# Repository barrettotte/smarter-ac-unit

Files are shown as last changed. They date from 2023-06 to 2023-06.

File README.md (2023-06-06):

# smarter-ac-unit

Making my AC unit a little smarter with MQTT and Home Assistant

## Summary

Uses Home Assistant, MQTT, and an infrared transmitter to control parts of my AC unit that I care about. 
This is only meant to work with my AC unit model, [LG LP1017WSR](https://www.lg.com/us/air-conditioners/lg-LP1017WSR-portable-air-conditioner).

Features:

- Set temperature between 60°F-86°F, defaulting to 70°F
- Toggle power - off, on (cool mode)
- Change fan speed - low, high

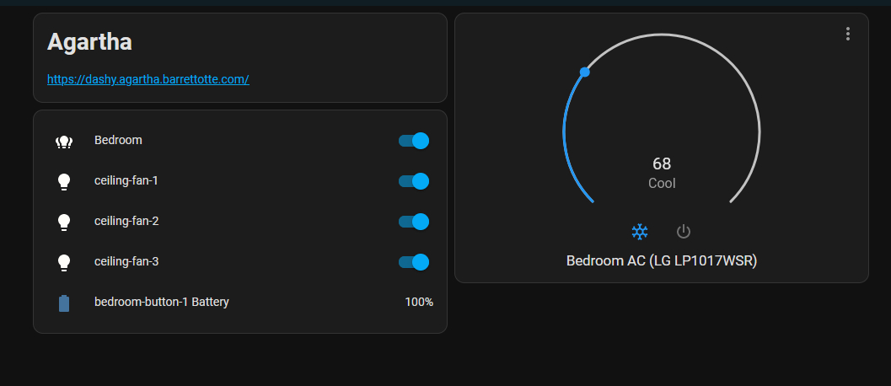
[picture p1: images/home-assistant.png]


I also added a manual sync button to my circuit to allow resyncing both Home Assistant and the AC unit
back to the state stored on the ESP8266.
This solves any rare problems where states get out of sync and start behaving strangely.

<a href="images/final-build.jpg">
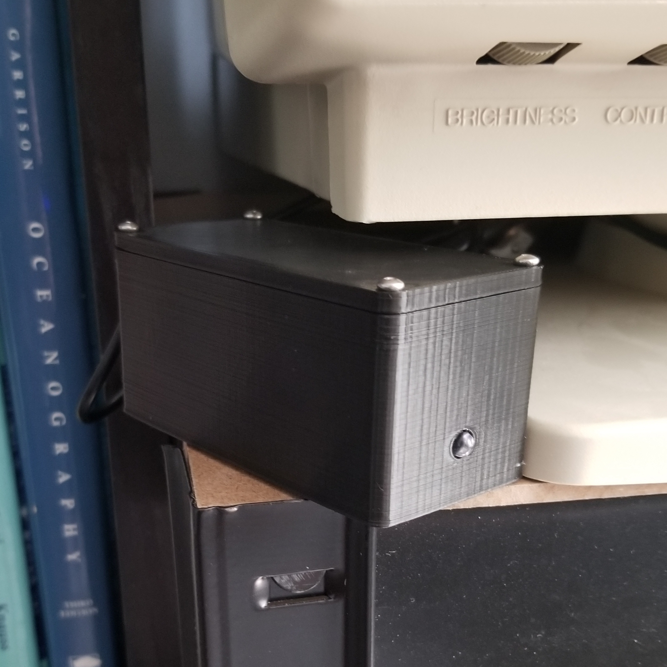
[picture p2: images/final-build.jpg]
final build
  
</a>

## Hardware

### Parts List

- 1x ESP8266
- 1x 2N3904 NPN transistor
- 1x IR LED
- 1x Red LED
- 1x 10KΩ resistor
- 1x 47Ω resistor
- 1x 470Ω resistor
- 1x pushbutton
- 4x 2.5x8mm hex button screws

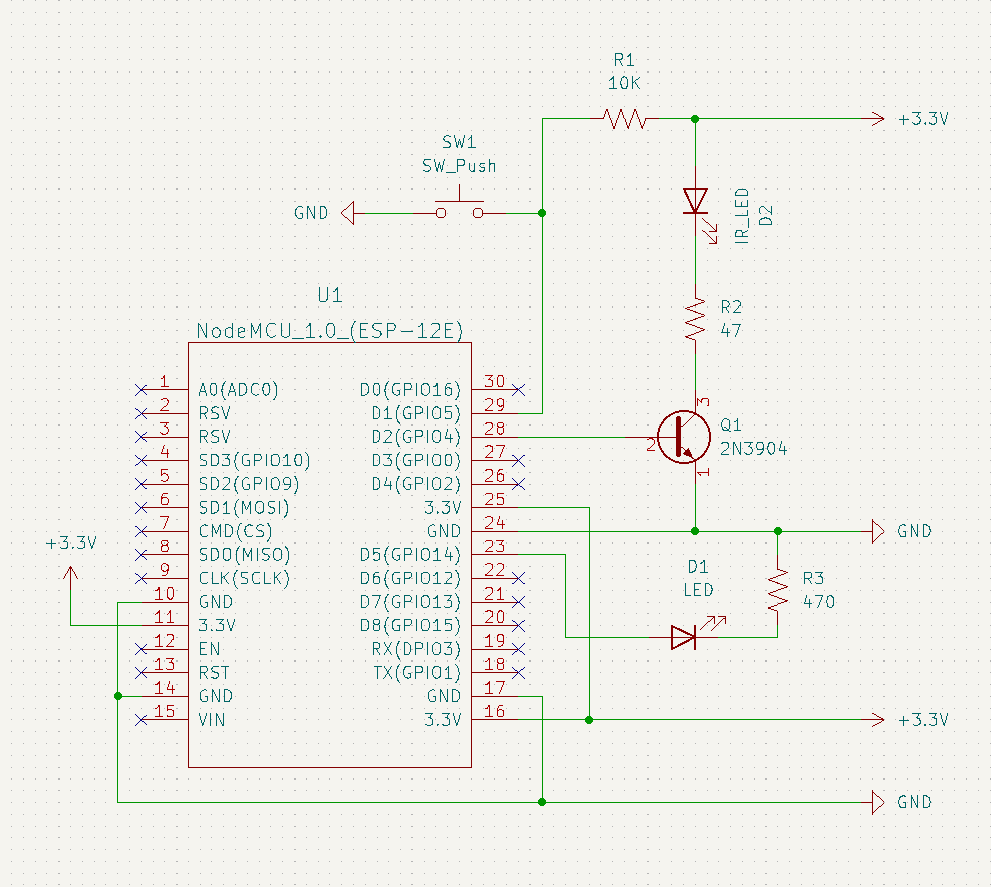
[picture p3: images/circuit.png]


<a href="images/protoboard.jpg">
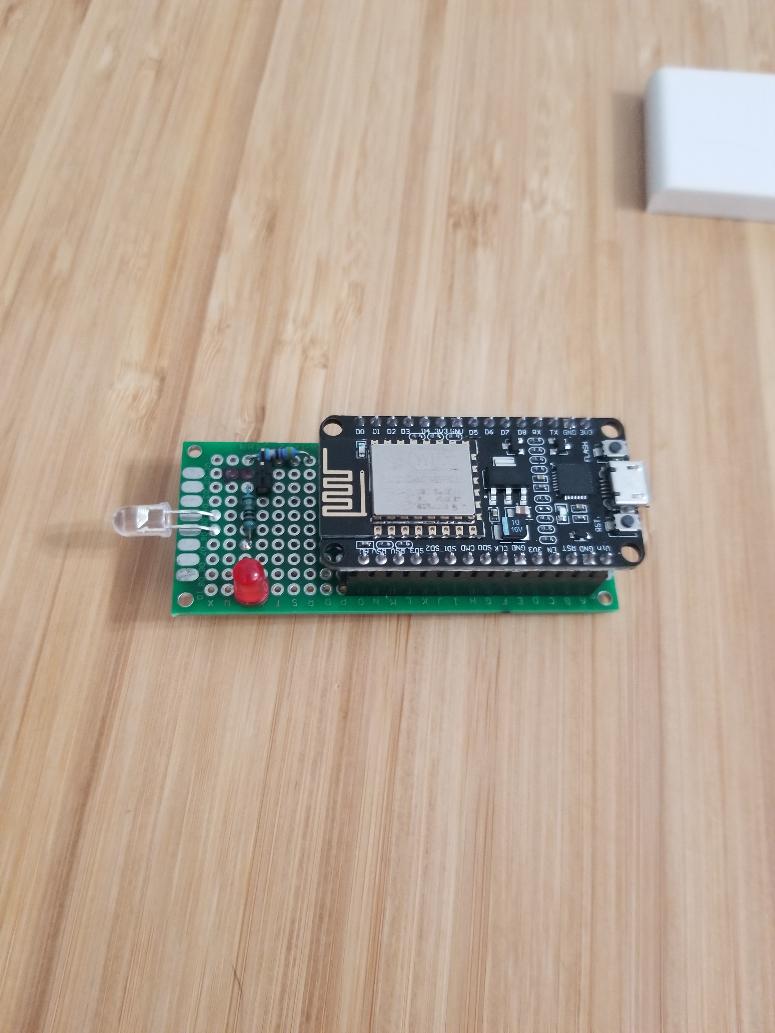
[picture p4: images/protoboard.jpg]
protoboard
  
</a>

## Infrastructure

### MQTT Broker

Used Eclipse Mosquitto for my MQTT broker, I used Docker to run it.

```yml
# docker-compose.yml

mosquitto:
  container_name: mosquitto
  image: eclipse-mosquitto:2
  ports:
    - '1883:1883' # MQTT
    - '9011:9011' # MQTT over websocket
  volumes:
  - /etc/timezone:/etc/timezone:ro
  - /etc/localtime:/etc/localtime:ro
  - ./mosquitto/mosquitto.conf:/mosquitto/config/mosquitto.conf
  - /home/docker/data/mosquitto/data:/mosquitto/data
  - /home/docker/data/mosquitto/logs:/mosquitto/log
  network_mode: host
  restart: unless-stopped
```

```conf
# mosquitto.conf

listener 1883

listener 9011
protocol websockets

persistence true
persistence_location /mosquitto/data/

log_dest stdout
```

### Home Assistant

I also self-host Home Assistant in Docker

```yml
home-assistant:
    container_name: home-assistant
    image: homeassistant/home-assistant:2023.3
    ports:
      - '8123:8123'
    volumes:
      - /etc/timezone:/etc/timezone:ro
      - /etc/localtime:/etc/localtime:ro
      - './home-assistant:/config'
    restart: unless-stopped
```

If MQTT discovery is disabled in `config.h`, then this can be manually configured 
in the `configuration.yml`

```yml
# configuration.yml

mqtt:
  climate:
    - name: Bedroom AC (LG LP1017WSR)
      unique_id: smarter_ac_unit
      qos: 0
      optimistic: true
      modes:
        - "off"
        - "cool"
      fan_modes:
        - "high"
        - "low"
      min_temp: 60
      max_temp: 86
      initial: 70
      temperature_unit: F
      temp_step: 1
      mode_command_topic: "smarter_ac_unit/mode/set"
      mode_command_template: "{{ value if value == 'off' else 'on' }}"
      mode_state_topic: "smarter_ac_unit/mode/state"
      fan_mode_command_topic: "smarter_ac_unit/fan/set"
      fan_mode_state_topic: "smarter_ac_unit/fan/state"
      temperature_command_topic: "smarter_ac_unit/temperature/set"
      temperature_state_topic: "smarter_ac_unit/temperature/state"
```

## IR Codes

```txt
Example IR Code (via ir-sniffer):

Protocol  : WHIRLPOOL_AC
Code      : 0x830601A20000C000000000000063001100803800A9 (168 Bits)
Mesg Desc.: Model: 2 (DG11J191), Power Toggle: Off, Mode: 2 (Cool), 
            Temp: 26C, Fan: 1 (High), Swing: Off, Light: On, 
            Clock: 00:00, On Timer: Off, Off Timer: Off, 
            Sleep: Off, Super: Off, Command: 17 (Fan)
```

Used [ir-sniffer](https://github.com/barrettotte/ir-sniffer) to manually gather all relevant IR codes
of button presses and states for my AC unit.
IR codes can be found in [docs/ir-codes.txt](docs/ir-codes.txt), these codes were used to create the table below.

Note: I'm only looking at cool mode...other modes may effect the values below.
Also, not figuring out sleep and timer...I don't use these at all.
Some of the mystery constants are probably part of this.

| Indices | Values | Notes |
| --- | --- | --- |
| 0:3 | 8306 | model...I guess? |
| 4:5 | 01,03 | Fan: 1=High, 3=Low |
| 6 | 0,1,2,3,4,5,6,7,8,9,A,B,C,D,E,F | Temperature: 60F-75F |
| | 0,1,2,3,4,5,6,7,8,9,A | Temperature: 76F-86F |
| 7 | 2 | Mode: 2=Cool |
| 8:15 | 0000C000 | ? |
| 16 | 0,4 | Swing: 0=off, 4=high |
| 17:25 | 000000000 | ? |
| 26 | C,D,E,F,8,9,A,B,4,5,6,7,0,1,2,3 | Temperature: 60F-75F |
| | C,D,E,F,8,9,A,B,4,5,6 | Temperature: 76F-86F |
| 27 | 3,1 | Fan: 3=High, 1=Low |
| 28:29 | 00 | ? |
| 30:31 | 02,25 | command (temperature change, power toggle) |
| 32:33 | 00 | ? |
| 34:36 | 003 | cool mode, high/low fan, Temperature: 60F-75F, [temp change or power on]  |
| | 803 | cool mode, high/low fan, Temperature: 76F-86F, [temp change or power on]  |
| | 002 | cool mode, high/low fan, Temperature: 60F-75F, power off |
| | 802 | cool mode, high/low fan, Temperature: 76F-86F, power off |
| 37:39 | 800 | ? |
| 40:41 | 3A | cool mode, high/low fan, Temperature: 60F-75F, temp change |
| | BA | cool mode, high/low fan, Temperature: 76F-86F, temp change |
| | 0D | cool mode, high/low fan, Temperature: 60F-75F, power off |
| | 8D | cool mode, high/low fan, Temperature: 76F-86F, power off |
| | 1D | cool mode, high/low fan, Temperature: 60F-75F, power on |
| | 9D | cool mode, high/low fan, Temperature: 76F-86F, power on |
| | 29 | cool mode, high/low fan, Temperature: 60F-75F, fan toggle |
| | A9 | cool mode, high/low fan, Temperature: 76F-86F, fan toggle |

## References

- https://github.com/Arduino-IRremote/Arduino-IRremote
- https://www.home-assistant.io/integrations/climate.mqtt/

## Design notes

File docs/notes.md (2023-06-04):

# Notes

AC Unit Model no: [LG LP1017WSR](https://www.lg.com/us/air-conditioners/lg-LP1017WSR-portable-air-conditioner)

## Remote

Remote ID: DG11J1-61

- Power on/off
- Temperature adjust: 60F-86F (16C-30C)
- Modes: Cool,Dehumidify,Fan
- Going to ignore Swing, Sleep, Timer buttons

LCD displays temperature, current mode, and signal icon when pressing buttons

So its definitely holding state in some way.

Pressing power button turns off LCD display.

Taking battery out resets state

When AC unit running and remote batteries are taken out, AC unit retains state.
After replacing batteries and turning remote on, AC unit's state is overridden by reset remote's state.

When in range, turning off remote, turns off AC unit.
If remote is turned off out of range, then turned back on, AC unit remains unchanged (it doesn't toggle power).
This also holds true for the reverse states.

## IR

IR 30-40 kHz, most common is 38 kHz

Used https://github.com/barrettotte/ir-sniffer to sniff all actions:

```txt
### Toggle through all operation modes

Protocol  : WHIRLPOOL_AC
Code      : 0x830603030000C0000000000000C0000600803800BE (168 Bits)
Mesg Desc.: Model: 2 (DG11J191), Power Toggle: Off, Mode: 3 (Dry), Temp: 16C, Fan: 3 (Low), Swing: Off, Light: On, Clock: 00:00, On Timer: Off, Off Timer: Off, Sleep: Off, Super: Off, Command: 6 (Mode)
-----------------------------------------------------------
Protocol  : WHIRLPOOL_AC
Code      : 0x830601040000C0000000000000C5000600803800BE (168 Bits)
Mesg Desc.: Model: 2 (DG11J191), Power Toggle: Off, Mode: 4 (Fan), Temp: 16C, Fan: 1 (High), Swing: Off, Light: On, Clock: 00:00, On Timer: Off, Off Timer: Off, Sleep: Off, Super: Off, Command: 6 (Mode)
-----------------------------------------------------------
Protocol  : WHIRLPOOL_AC
Code      : 0x830601A20000C000000000000063000600803800BE (168 Bits)
Mesg Desc.: Model: 2 (DG11J191), Power Toggle: Off, Mode: 2 (Cool), Temp: 26C, Fan: 1 (High), Swing: Off, Light: On, Clock: 00:00, On Timer: Off, Off Timer: Off, Sleep: Off, Super: Off, Command: 6 (Mode)
-----------------------------------------------------------

0x830603030000C0000000000000C0000600803800BE  3 (dry)
0x830601040000C0000000000000C5000600803800BE  4 (fan)
0x830601A20000C000000000000063000600803800BE  2 (cool)
```

```txt
### Flip through fan modes

Protocol  : WHIRLPOOL_AC
Code      : 0x830601A20000C000000000000063001100803800A9 (168 Bits)
Mesg Desc.: Model: 2 (DG11J191), Power Toggle: Off, Mode: 2 (Cool), Temp: 26C, Fan: 1 (High), Swing: Off, Light: On, Clock: 00:00, On Timer: Off, Off Timer: Off, Sleep: Off, Super: Off, Command: 17 (Fan)
-----------------------------------------------------------
Protocol  : WHIRLPOOL_AC
Code      : 0x830603A20000C000000000000061001100803800A9 (168 Bits)
Mesg Desc.: Model: 2 (DG11J191), Power Toggle: Off, Mode: 2 (Cool), Temp: 26C, Fan: 3 (Low), Swing: Off, Light: On, Clock: 00:00, On Timer: Off, Off Timer: Off, Sleep: Off, Super: Off, Command: 17 (Fan)
-----------------------------------------------------------

0x830601A20000C000000000000063001100803800A9  1 (High)
0x830603A20000C000000000000061001100803800A9  3 (Low)
```

| Command | Button |
| --- | --- |
| 0 | Timer toggle |
| 2 | Temperature up/down |
| 3 | Sleep |
| 5 | Set timer |
| 6 | Mode switch |
| 7 | Swing |
| 17 | Fan toggle |
| 37 | Power on/off |

### IR Code Decoding

```txt
Example IR Code (via ir-sniffer):

Protocol  : WHIRLPOOL_AC
Code      : 0x830601A20000C000000000000063001100803800A9 (168 Bits)
Mesg Desc.: Model: 2 (DG11J191), Power Toggle: Off, Mode: 2 (Cool), 
            Temp: 26C, Fan: 1 (High), Swing: Off, Light: On, 
            Clock: 00:00, On Timer: Off, Off Timer: Off, 
            Sleep: Off, Super: Off, Command: 17 (Fan)
```

Used [ir-sniffer](https://github.com/barrettotte/ir-sniffer) to manually gather all relevant IR codes
of button presses and states for my AC unit.
IR codes can be found in [ir-codes.txt](ir-codes.txt), these codes were used to create the table below.

Note: I'm only looking at cool mode...other modes may effect the values below.
Also, not figuring out sleep and timer...I don't use these at all.
Some of the mystery constants are probably part of this.

| Indices | Values | Notes |
| --- | --- | --- |
| 0:3 | 8306 | model...I guess? |
| 4:5 | 01,03 | Fan: 1=High, 3=Low |
| 6 | 0,1,2,3,4,5,6,7,8,9,A,B,C,D,E,F | Temperature: 60F-75F |
| | 0,1,2,3,4,5,6,7,8,9,A | Temperature: 76F-86F |
| 7 | 2 | Mode: 2=Cool |
| 8:15 | 0000C000 | ? |
| 16 | 0,4 | Swing: 0=off, 4=high |
| 17:25 | 000000000 | ? |
| 26 | C,D,E,F,8,9,A,B,4,5,6,7,0,1,2,3 | Temperature: 60F-75F |
| | C,D,E,F,8,9,A,B,4,5,6 | Temperature: 76F-86F |
| 27 | 3,1 | Fan: 3=High, 1=Low |
| 28:29 | 00 | ? |
| 30:31 | 02,25 | command (temperature change, power toggle) |
| 32:33 | 00 | ? |
| 34:36 | 003 | cool mode, high/low fan, Temperature: 60F-75F, [temp change or power on]  |
| | 803 | cool mode, high/low fan, Temperature: 76F-86F, [temp change or power on]  |
| | 002 | cool mode, high/low fan, Temperature: 60F-75F, power off |
| | 802 | cool mode, high/low fan, Temperature: 76F-86F, power off |
| 37:39 | 800 | ? |
| 40:41 | 3A | cool mode, high/low fan, Temperature: 60F-75F, temp change |
| | BA | cool mode, high/low fan, Temperature: 76F-86F, temp change |
| | 0D | cool mode, high/low fan, Temperature: 60F-75F, power off |
| | 8D | cool mode, high/low fan, Temperature: 76F-86F, power off |
| | 1D | cool mode, high/low fan, Temperature: 60F-75F, power on |
| | 9D | cool mode, high/low fan, Temperature: 76F-86F, power on |
| | 29 | cool mode, high/low fan, Temperature: 60F-75F, fan toggle |
| | A9 | cool mode, high/low fan, Temperature: 76F-86F, fan toggle |

## References

- https://mylonasc.github.io/2019-02-09-reverseeng/
- http://www.righto.com/2009/09/arduino-universal-remote-record-and.html (Ken Shirriff)
- [Andreas Spiess - Arduino Guide to Infrared (IR) Communication](https://www.youtube.com/watch?v=gADIb1Xw8PE)
- NEC protocol - https://www.sbprojects.net/knowledge/ir/nec.php

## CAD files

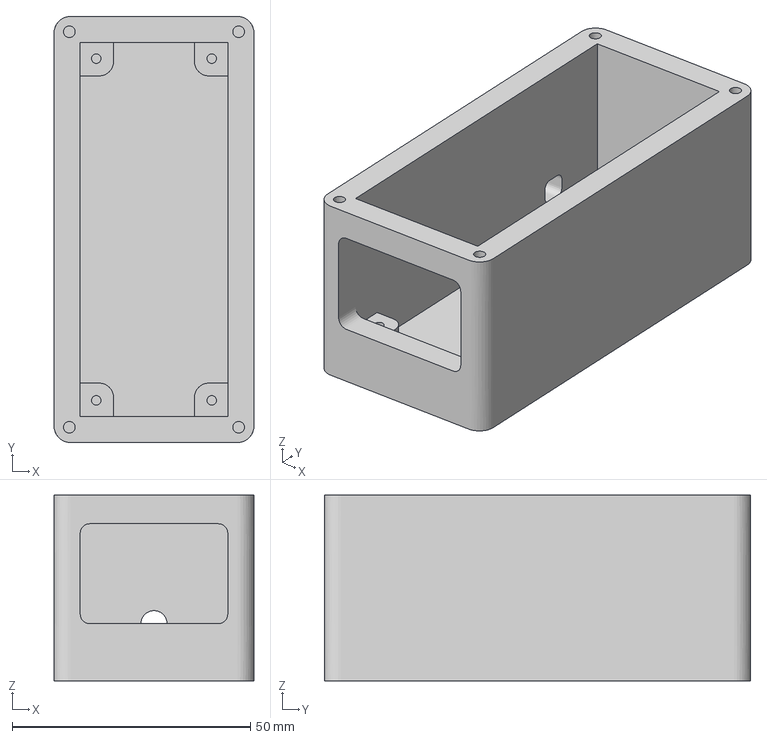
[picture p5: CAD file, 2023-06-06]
fusion360/main.3mf
42.0 x 89.5 x 39.0 mm

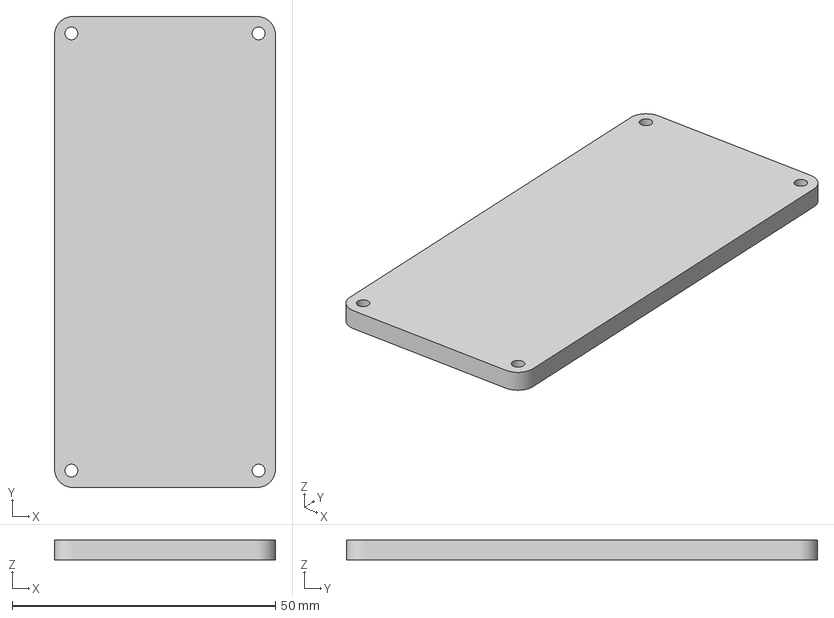
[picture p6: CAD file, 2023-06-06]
fusion360/lid.3mf
42.0 x 89.5 x 3.75 mm

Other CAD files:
fusion360/smarter-ac-unit.f3d

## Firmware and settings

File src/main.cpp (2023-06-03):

#include <ESP8266WiFi.h>
#include <IRremoteESP8266.h>
#include <IRsend.h>
#include <PubSubClient.h>

#include <config.h>

#define MQTT_MAX_PACKET_SIZE 2048 // redefined from 256 in PubSubClient
// Note: this causes a compiler warning, but I couldn't get anything else to work.

// lookup table for temperature encoding
// there's definitely a pattern to this, but I think a lookup table is easier to grok
const uint8_t temperatureLookup[] = {
    0xC, 0xD, 0xE, 0xF, 0x8, 0x9, 0xA, 0xB, // 60-67
    0x4, 0x5, 0x6, 0x7, 0x0, 0x1, 0x2, 0x3, // 68-75
    0xC, 0xD, 0xE, 0xF, 0x8, 0x9, 0xA, 0xB, // 76-83
    0x4, 0x5, 0x6                           // 84-86
};

void mqttCallback(char* topic, byte* payload, unsigned int payloadLength);
void mqttReconnect();
void mqttDiscover();
void mqttPublishState();

enum AcCommand {
    CMD_TEMP_CHANGE = 0x02,
    CMD_FAN_TOGGLE = 0x11,
    CMD_POWER_TOGGLE = 0x25,
};

struct EzTimer {
    bool trigger;
    unsigned long currentMs;
    unsigned long prevMs;
};

struct AcState {
    uint8_t mode;  // 0=off, 1=cool
    uint8_t speed; // 0=low, 1=high
    uint8_t temperature;
};

/** globals ***/

WiFiClient wifiClient;
PubSubClient mqttClient(wifiClient);
IRsend irSend(IR_LED_PIN);

struct AcState state;

struct EzTimer statePublishTimer;
struct EzTimer irFeedbackTimer;
struct EzTimer manualSyncTimer;

/*** init ***/

void initSerial() {
    Serial.begin(115200);
    Serial.println();

    for (uint8_t t = 3; t > 0; t--) {
        Serial.printf("WAIT %d...\n", t);
        Serial.flush();
        delay(500);
    }
    Serial.println("\n* * * START * * *");
}

void initWifi() {
    WiFi.mode(WIFI_STA); // esp defaults to STA+AP
    WiFi.begin(WIFI_SSID, WIFI_PASSWORD);

    Serial.print("Connecting to WiFi");
    while (WiFi.status() != WL_CONNECTED) {
        delay(500);
        Serial.print(".");
    }
    Serial.print("\nIP address: ");
    Serial.println(WiFi.localIP());
}

void initMqtt() {
    mqttClient.setServer(MQTT_SERVER, MQTT_PORT);
    mqttClient.setCallback(mqttCallback);
    mqttClient.setKeepAlive(60);
    mqttClient.setSocketTimeout(10);
    mqttClient.setBufferSize(MQTT_MAX_PACKET_SIZE);

    // home assistant discovery
    if (USE_HA_MQTT_DISCOVERY) {
        mqttReconnect();
        mqttDiscover();
    }
}

/*** infrared ***/

// encode state to infrared code based on command
void buildIrCode(uint8_t* code, AcCommand cmd) {
    /*
        Example infrared code (via ir-sniffer)

        Protocol  : WHIRLPOOL_AC
        Code      : 0x830601A20000C000000000000063001100803800A9 (168 Bits = 21 Bytes)
        Mesg Desc.: Model: 2 (DG11J191), Power Toggle: Off, Mode: 2 (Cool), 
                Temp: 26C, Fan: 1 (High), Swing: Off, Light: On, 
                Clock: 00:00, On Timer: Off, Off Timer: Off, 
                Sleep: Off, Super: Off, Command: 17 (Fan)
    */
    bool lowTemp = (state.temperature >= 60 && state.temperature <= 75);

    code[0] = 0x83; // manufacturer/model ?
    code[1] = 0x06; // manufacturer/model ?
    code[2] = state.speed == 0 ? 0x03 : 0x01; // fan speed

    if (lowTemp) {
        code[3] = state.temperature - 60; // 60=0x0, 65=0x5, 70=0xA, 75=0xF
    } else {
        code[3] = state.temperature - 76; // 76=0x0, 80=0x4, 86=0xA
    }
    code[3] <<= 4;
    code[3] |= 0x2; // cool mode; other modes not supported
    
    // some constant 0x0000C000
    code[4] = 0x00;
    code[5] = 0x00;
    code[6] = 0xC0;
    code[7] = 0x00;

    code[8] = 0x0; // swing: 0=off; not supported
    code[8] <<= 4;
    code[8] |= 0x0; // low nibble (constant zero)

    // some constant 0x00000000
    code[9] = 0x00;
    code[10] = 0x00;
    code[11] = 0x00;
    code[12] = 0x00;

    code[13] = temperatureLookup[state.temperature - 60];
    code[13] <<= 4;
    code[13] |= state.speed == 0 ? 0x1 : 0x3;

    code[14] = 0x00; // constant
    code[15] = cmd;

    code[16] = 0x00; // constant
    code[17] = lowTemp ? 0x00 : 0x80;

    code[18] = (cmd == CMD_TEMP_CHANGE || state.mode == 1) ? 0x38 : 0x28;
    code[19] = 0x00;

    if (cmd == CMD_TEMP_CHANGE) {
        code[20] = lowTemp ? 0x3A : 0xBA;
    } else if (cmd == CMD_FAN_TOGGLE) {
        code[20] = lowTemp ? 0x29 : 0xA9;
    } else if (state.mode == 0) {
        code[20] = lowTemp ? 0x0D : 0x8D;
    } else {
        code[20] = lowTemp ? 0x1D : 0x9D;
    }
}

// trigger LED to fire to signal IR is being transmitted
void triggerIrFeedback() {
    if (!irFeedbackTimer.trigger) {
        irFeedbackTimer.trigger = true;
        digitalWrite(IR_FEED_LED_PIN, HIGH);
    }
}

// send infrared code to AC unit
void sendIrCode(AcCommand cmd) {
    uint8_t code[IR_PAYLOAD_SIZE];
    memset(code, 0, IR_PAYLOAD_SIZE);
    buildIrCode(code, cmd);

    Serial.print("Sending IR code -> 0x");
    for (uint8_t i = 0; i < IR_PAYLOAD_SIZE; i++) {
        Serial.printf("%02X", code[i]);
    }
    Serial.println();

    triggerIrFeedback();
    irSend.sendWhirlpoolAC(code, IR_PAYLOAD_SIZE);
}

/*** AC state change ***/

void printState() {
    Serial.printf("State: mode=%d,speed=%d,temperature=%d\n", state.mode, state.speed, state.temperature);
}

// manually sync state with both Home Assistant and AC unit
void manualSync() {
    Serial.println("Manually syncing state...");
    printState();
    sendIrCode(CMD_TEMP_CHANGE);
    mqttPublishState();
}

// set AC mode and fire IR signal on state change
void setAcMode(char* message) {
    uint8_t prevMode = state.mode;

    if (strcmp(message, "off") == 0) {
        state.mode = 0;
    } else if (strcmp(message, "on") == 0 || strcmp(message, "cool")) {
        state.mode = 1;
    } else {
        Serial.printf("Warning: Invalid mode '%s'. Mode not set\n", message);
        return;
    }

    // only send IR code on state change
    if (prevMode != state.mode) {
        Serial.printf("Set mode to %d\n", state.mode);
        printState();
        sendIrCode(CMD_POWER_TOGGLE);
    }
}

// set AC temperature and fire IR signal on state change
void setAcTemperature(char* message) {
    uint8_t prevTemp = state.temperature;
    int t = atoi(message); // note: randomly comes in as float sometimes, but this still works

    if (t > AC_TEMP_MAX) {
        Serial.printf("Warning: Temperature too high %d. Clamped to %d", t, AC_TEMP_MAX);
        t = AC_TEMP_MAX;
    } else if (t < AC_TEMP_MIN) {
        Serial.printf("Warning: Temperature too low %d. Clamped to %d", t, AC_TEMP_MIN);
        t = AC_TEMP_MIN;
    }
    state.temperature = t;

    // only send IR code on state change
    if (prevTemp != state.temperature) {
        Serial.printf("Set temperature to %d\n", state.temperature);
        printState();
        sendIrCode(CMD_TEMP_CHANGE);
    }
}

// set AC fan speed and fire IR signal on state change
void setAcFanSpeed(char* message) {
    uint8_t prevSpeed = state.speed;

    if (strcmp(message, "low") == 0) {
        state.speed = 0;
    } else if (strcmp(message, "high") == 0) {
        state.speed = 1;
    } else {
        Serial.printf("Warning: Invalid fan speed '%s'. Fan speed not set\n", message);
        return;
    }

    // only send IR code on state change
    if (prevSpeed != state.speed) {
        Serial.printf("Set fan speed to %d\n", state.speed);
        printState();
        sendIrCode(CMD_FAN_TOGGLE);
    }
}

/*** MQTT ***/

// handle message from subscribed MQTT topics that change state - smarter_ac_unit/*/set
void mqttCallback(char* topic, byte* payload, unsigned int payloadLength) {    

    Serial.printf("Message arrived on topic %s, message: ", topic);
    for (unsigned int i = 0; i < payloadLength; i++) {
        Serial.print((char) payload[i]);
    }
    Serial.println();

    if (payloadLength > MQTT_MAX_COMMAND_SIZE) {
        Serial.printf("Error: Command message size too large; %d > %d\n", payloadLength, MQTT_MAX_COMMAND_SIZE);
        return;
    }

    char message[payloadLength + 1];
    memcpy(message, payload, payloadLength);
    message[payloadLength] = '\0';

    if (strcmp(topic, MQTT_TOPIC_MODE_COMMAND) == 0) {
        setAcMode(message);
    } else if (strcmp(topic, MQTT_TOPIC_TEMP_COMMAND) == 0) {
        setAcTemperature(message);
    } else if (strcmp(topic, MQTT_TOPIC_FAN_COMMAND) == 0) {
        setAcFanSpeed(message);
    } else {
        Serial.printf("Warning: Listening to unsupported topic %s. State unchanged\n", topic);
        return;
    }
}

// reconnect to MQTT broker and subscribe to command topics
void mqttReconnect() {
    String clientId = MQTT_BASE_CLIENT_ID;
    clientId += "-" + String(WiFi.macAddress());

    while (!mqttClient.connected()) {
        Serial.print("Connecting to MQTT broker...");

        if (!mqttClient.connect(clientId.c_str(), MQTT_USER, MQTT_PASSWORD)) {
            Serial.printf("Failed to connect to MQTT broker. rc=%d\nRetrying in 5 seconds...\n", mqttClient.state());
            delay(5000);
        }
    }
    Serial.println("Connected to MQTT!");

    mqttClient.subscribe(MQTT_TOPIC_MODE_COMMAND);
    mqttClient.subscribe(MQTT_TOPIC_TEMP_COMMAND);
    mqttClient.subscribe(MQTT_TOPIC_FAN_COMMAND);
}

// publish discovery message for Home Assistant to auto-configure entity
void mqttDiscover() {
    char mqttPayload[MQTT_MAX_PACKET_SIZE];

    sprintf(
        mqttPayload,HA_MQTT_DISCOVERY, 
        HA_NAME, HA_UNIQUE_ID,
        AC_TEMP_MIN, AC_TEMP_MAX, AC_TEMP_DEFAULT,
        MQTT_TOPIC_MODE_COMMAND, MQTT_TOPIC_MODE_STATE,
        MQTT_TOPIC_TEMP_COMMAND, MQTT_TOPIC_TEMP_COMMAND,
        MQTT_TOPIC_FAN_COMMAND, MQTT_TOPIC_FAN_STATE
    );
    Serial.printf("Sending discovery payload %s\n", mqttPayload);
    mqttClient.publish(MQTT_TOPIC_HA_DISCOVER, mqttPayload);
}

// publish AC state values to their respective MQTT topics
void mqttPublishState() {
    Serial.printf("Publishing state -> ");
    printState();

    char stateBuffer[8];
    sprintf(stateBuffer, "%s", state.speed ? "high" : "low");
    mqttClient.publish(MQTT_TOPIC_FAN_STATE, stateBuffer, true);

    memset(stateBuffer, 0, 8);
    sprintf(stateBuffer, "%s", state.mode ? "on" : "off");
    mqttClient.publish(MQTT_TOPIC_MODE_COMMAND, stateBuffer, true);

    memset(stateBuffer, 0, 8);
    sprintf(stateBuffer, "%d", state.temperature);
    mqttClient.publish(MQTT_TOPIC_TEMP_COMMAND, stateBuffer, true);
}

/*** main ***/

void setup() {
    pinMode(LED_BUILTIN, OUTPUT);
    digitalWrite(LED_BUILTIN, HIGH); // signal init in progress
    pinMode(IR_FEED_LED_PIN, OUTPUT);
    pinMode(MANUAL_SYNC_PIN, INPUT_PULLUP);

    initSerial();
    initWifi();
    irSend.begin();
    initMqtt();

    // init state
    state.mode = 0;
    state.speed = 0;
    state.temperature = AC_TEMP_DEFAULT;

    digitalWrite(LED_BUILTIN, LOW); // signal init done
    Serial.println("Setup done.");
}

void loop() {
    if (!mqttClient.connected()) {
        mqttReconnect(); // will block on failed connections, but probably fine for this
    }

    // reset IR feedback LED if active and enough time passed
    irFeedbackTimer.currentMs = millis();
    if ((irFeedbackTimer.currentMs - irFeedbackTimer.prevMs) > IR_FEEDBACK_MS) {
        irFeedbackTimer.prevMs = irFeedbackTimer.currentMs;
        irFeedbackTimer.trigger = false;
        digitalWrite(IR_FEED_LED_PIN, LOW);
    }

    // handle debounced button for manual sync
    manualSyncTimer.currentMs = millis();
    if (((manualSyncTimer.currentMs - manualSyncTimer.prevMs) > MANUAL_SYNC_DEBOUNCE_MS) && digitalRead(MANUAL_SYNC_PIN) == LOW) {
        manualSyncTimer.prevMs = manualSyncTimer.currentMs;
        triggerIrFeedback();
        manualSync();
    }

    // handle periodic state publish to home assistant
    statePublishTimer.currentMs = millis();
    if ((statePublishTimer.currentMs - statePublishTimer.prevMs) > MQTT_PUBLISH_STATE_MS) {
        statePublishTimer.prevMs = statePublishTimer.currentMs;
        mqttPublishState();
    }
    mqttClient.loop();
    delay(100);
}

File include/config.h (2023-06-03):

#pragma once

#include "secrets.h"

/*** pins ***/

#define MANUAL_SYNC_PIN D1 // button to manually sync state
#define IR_LED_PIN D2      // IR LED transmit pin
#define IR_FEED_LED_PIN D5 // Feedback LED for transmitting IR signal

/*** misc ***/

#define IR_FEEDBACK_MS 75           // time for IR feedback LED to stay on
#define IR_PAYLOAD_SIZE 21          // whirlpool AC
#define MANUAL_SYNC_DEBOUNCE_MS 300 // debounce button to ensure multiple syncs aren't fired

/*** temperature ***/

#define AC_TEMP_MAX 86
#define AC_TEMP_MIN 60
#define AC_TEMP_DEFAULT 70

/*** Home Assistant ***/

const char* HA_NAME = "Bedroom AC (LG LP1017WSR)";
const char* HA_UNIQUE_ID = "bedroom_ac_unit";

#define USE_HA_MQTT_DISCOVERY 1 // set 0 to disable Home Assistant auto-configure via MQTT discovery

// Home Assistant discovery payload
const char* HA_MQTT_DISCOVERY = ""\
    "{"\
        "\"name\":\"%s\","\
        "\"unique_id\":\"%s\","\
        "\"modes\":[\"off\",\"cool\"],"\
        "\"fan_modes\":[\"low\",\"high\"],"\
        "\"min_temp\":%d,"\
        "\"max_temp\":%d,"\
        "\"initial\":%d,"\
        "\"temperature_unit\":\"F\","\
        "\"temp_step\":1,"\
        "\"optimistic\":true,"\
        "\"qos\":0,"\
        "\"mode_command_topic\":\"%s\","\
        "\"mode_command_template\":\"{{ value if value=='off' else 'on' }}\","\
        "\"mode_state_topic\":\"%s\","\
        "\"temperature_command_topic\":\"%s\","\
        "\"temperature_state_topic\":\"%s\","\
        "\"fan_mode_command_topic\":\"%s\","\
        "\"fan_mode_state_topic\":\"%s\""\
    "}";

/*** MQTT ***/

#define MQTT_PUBLISH_STATE_MS 15000 // interval to broadcast state to smarter_ac_unit/*/state topics
#define MQTT_MAX_COMMAND_SIZE 8     // limits size of messages for smarter_ac_unit/*/set topics

const char* MQTT_SERVER = "giza.agartha";
const int MQTT_PORT = 1883;
const char* MQTT_BASE_CLIENT_ID = "smarter-ac-unit-esp8266";

const char* MQTT_TOPIC_HA_DISCOVER = "homeassistant/climate/smarter_ac_unit/config";
const char* MQTT_TOPIC_MODE_COMMAND = "smarter_ac_unit/mode/set";
const char* MQTT_TOPIC_MODE_STATE = "smarter_ac_unit/mode/state";
const char* MQTT_TOPIC_TEMP_COMMAND = "smarter_ac_unit/temperature/set";
const char* MQTT_TOPIC_TEMP_STATE = "smarter_ac_unit/temperature/state";
const char* MQTT_TOPIC_FAN_COMMAND = "smarter_ac_unit/fan/set";
const char* MQTT_TOPIC_FAN_STATE = "smarter_ac_unit/fan/state";

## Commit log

2023-04-08 temp - try switch to windows
2023-06-03 add IR feedback LED and manual sync button
2023-06-04 adds kicad schematic
    [smarter-ac-unit.kicad_pcb, smarter-ac-unit.kicad_sch]
2023-06-04 adds schematic to gitattributes, temp delete kicad schematic
    [smarter-ac-unit.kicad_pcb, smarter-ac-unit.kicad_sch]
2023-06-04 adds kicad files back
    [smarter-ac-unit.kicad_pcb, smarter-ac-unit.kicad_sch]
2023-06-04 fixes schematic and adds part list
    [smarter-ac-unit.kicad_sch]
2023-06-06 re-export all cad
    [lid.3mf, main.3mf, smarter-ac-unit.f3d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]
2023-06-06 re-export circuit image
